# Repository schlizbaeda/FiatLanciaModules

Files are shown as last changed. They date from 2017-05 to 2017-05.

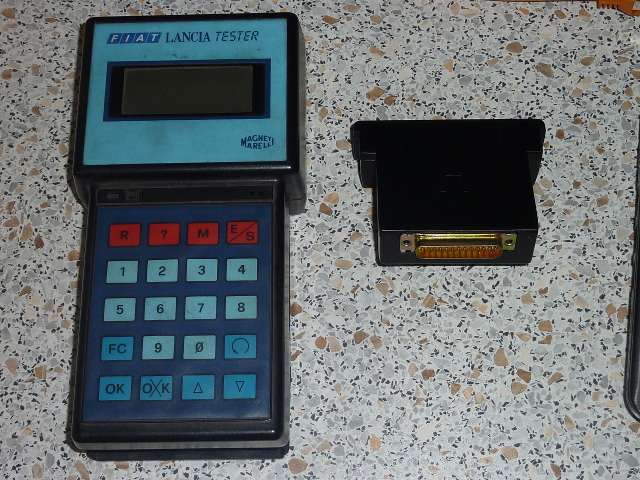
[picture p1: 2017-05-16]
Bilder/Titelbild.JPG

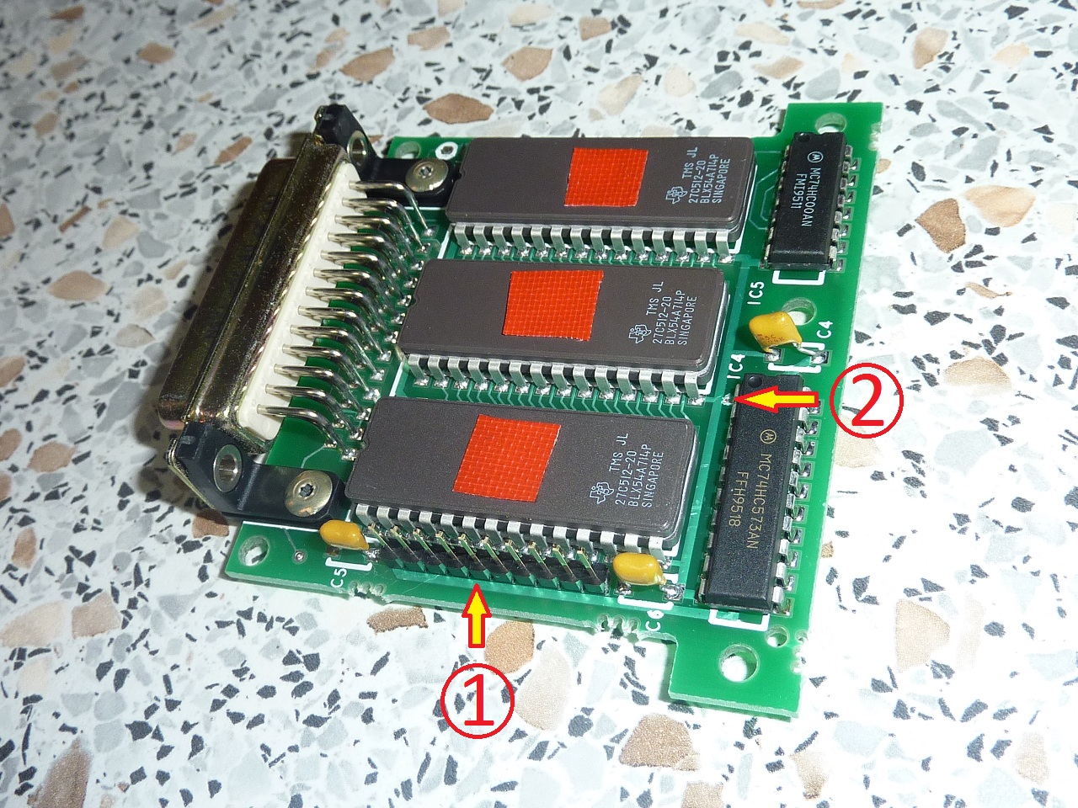
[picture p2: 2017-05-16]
Bilder/_Umbau01.jpg

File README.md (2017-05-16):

ACHTUNG:

Dieses Repository stammt weder vom Automobilhersteller "FIAT S.p.A.",
noch vom zum FIAT-Konzern gehörenden Automobilzulieferunternehmen 
"Magneti Marelli S.p.A."! Die Verwendung dieser Namen durch mich dient
lediglich der leichteren Zuordnung für den Leser, wofür die hier 
präsentierte Anleitung und weitere Daten dienen sollen.

# FiatLanciaModules
EPROM-Programmierung der Module für den Fiat/Lancia-Tester

In der Datei FL-Module_programmieren.pdf befindet sich eine Anleitung, wie 
aus vorhandenen EPROM-Modulen für den F/L-Tester aus den 90er-Jahren(?)
- die Moduldaten ausgelesen
- die Module (zum Widerbeschreiben) gelöscht 
- die Module neu programmiert

werden können.

Dieses GitHub-Repository enthält alle Dateien zur Erstellung dieser Doku-
mentation mittels LaTeX im Hauptverzeichnis sowie in den Unterverzeichnissen
Bilder, Kapitel und Layout

# Erstellung der pdf-Datei mittels LaTeX unter Ubuntu im Terminalfenster
$ sudo apt-get install texlive-full

$ pdflatex FL-Module_programmieren.tex

Während der Erstellung erscheint die Meldung

    l.180 \caption
                      {{\FLTester} und Memory}           
    ? 
mit blinkendem Cursor. Hier über die Tastatur R ENTER eingeben.

$ pdflatex FL-Module_programmieren.tex

Dieser zweite Aufruf ist in LaTeX erforderlich, um das Inhaltsverzeichnis
und die Verlinkungen des Dokumentes korrekt zu erstellen.

# Nachbau
Der Nachbau inkl. Schaltplänen ist in FL-Module_programmieren.pdf beschrieben.
Im Verzeichnis Hardware befinden sich weitere Informationen für den Nachbau:
- Layoutdaten für EAGLE
- IC-Datenblätter

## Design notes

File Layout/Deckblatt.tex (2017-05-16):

% -- Deckblatt.tex -----------------------------------------------------------
%
%   Gestaltung des Deckblattes der Bedienungsanleitung:  
%   - Einbinden und formatieren der Logos
%   - Bezeichnungen befinden sich in 'Meta.tex'   
% ------------------------------------------------------------------------------

\thispagestyle{empty} % von plain nach empty
\begin{titlepage}
\vspace*{-3cm}% vertikale negative Verschiebung
%%------------------------------------------------------------------------------
%%   Firmenlogo einfügen
%%------------------------------------------------------------------------------
\begin{figure}[h]
\centering

\end{figure}

\begin{center}
\LARGE{\textbf{\Dokumentart}}\\[1.5ex] 
\Large{\BezeichnungLang}\\[4ex]
%%------------------------------------------------------------------------------
%%   Titel der Bedienungsanleitung
%%------------------------------------------------------------------------------
\noindent\rule[1ex]{\textwidth}{3pt} % vertikaler Strich
%\huge{\textbf{\titel}}\\[1.5ex]      % TITEL DER ARBEIT
\textbf{\titel}\\[1.5ex]              % TITEL DER ARBEIT (lange Überschrift)
\noindent\rule[1ex]{\textwidth}{3pt} 
%\LARGE{\textbf{\untertitel}}\\[6ex]
%\LARGE{\textbf{\art}}\\[1.5ex]
%\Large{im Fachgebiet \fachgebiet}
\\[2ex]

\normalsize
%%------------------------------------------------------------------------------
%%   Bild
%%------------------------------------------------------------------------------
\begin{figure}[h]
\centering

\end{figure}

%%------------------------------------------------------------------------------
%%   CE und Firmenadresse
%%------------------------------------------------------------------------------
\begin{tabular}{p{3cm} p{8cm} p{3cm}}\\ % die beiden 0.5cm breiten "TabellensSpalten" sind eigentlich latex-unwürdiges Gepfriemel! Ich kann's aber nicht besser!
\hline
\parbox[c]{75px}{} & \textbf{Module für {\FLTester} programmieren} Datum: 23.10.2016 & \parbox[c]{75px}{}\\
\hline
\end{tabular}

\end{center}

Diese Anleitung wurde mit dem Textsatzsystem \LaTeX\ erstellt.
%% Das trifft hier nicht zu:
%\textbf{}\\
%Das Bild auf dem Fernsehgerät stammt aus dem Video zu folgendem Musikstück:\\
%\texttt{\textbf{Riegler Hias feat. d' Hundskrippln} \textit{Gloana Bauer}} bei 0:15\\
%\url{http://www.hundskrippln.de/#filme}
\end{titlepage}

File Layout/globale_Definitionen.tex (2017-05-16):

% Meta-Informationen -----------------------------------------------------------
%   Definition von globalen Parametern, die im gesamten Dokument verwendet
%   werden können (z.B auf dem Deckblatt etc.).
%
%   ACHTUNG: Wenn die Texte Umlaute oder ein Esszet enthalten, muss der folgende
%            Befehl bereits an dieser Stelle aktiviert werden:
%            \usepackage[latin1]{inputenc}
% ------------------------------------------------------------------------------
\newcommand{\titel}{Umprogrammierung von EPROM-Modulen für den {\FLTester}}
\newcommand{\untertitel}{}%{TODO: und hier kommt der Untertitel}
\newcommand{\Bezeichnung}{Module für {\FLTester} programmieren}
\newcommand{\BezeichnungLang}{EPROM-Module für {\MarelliTester} ändern}
%\newcommand{\Version}{V0.1}
\newcommand{\Dokumentart}{A N L E I T U N G}
\newcommand{\autor}{schlizbäda}
\newcommand{\jahr}{2016}

% verwendete Hardware
\newcommand{\FLTester}{F/L-Tester}
\newcommand{\MarelliTester}{Fiat Lancia Tester (Magneti Marelli)} % TODO: Internetbilder "FIAT" "LANCIA" "Tester" "MagnetiMarelli" 
\newcommand{\Batronix}{Batronix BARLINO II} % Programmiergerät
% verwendete Software
\newcommand{\ProgExpress}{Prog-Express} % Batronix Programmiersoftware

%%Steuerelemente von Software:
%\newcommand{\prompt}[1]{\Code{\textit{#1}}}
%\newcommand{\filenam}[1]{\Code{#1}}
%
%\newcommand{\button}[1]{\Code{[{#1}]}}
%\newcommand{\menuitem}[1]{\textbf{\textit{"{#1}"}}}
%\newcommand{\checkbox}[1]{\textbf{\textit{"{#1}"}}}

%Smileys:
\newcommand{\smiley}[1]{}}

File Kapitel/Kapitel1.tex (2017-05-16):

\chapter{Einführung}
\label{cha:Einfuehrung}

\section{ACHTUNG}
{\LARGE Stand 16.05.2017

Leider sehe ich mich derzeit nicht in der Lage, meine Erkenntnisse rechtlich 
gefahrlos zu veröffentlichen! Ich werde versuchen, über offizielle Stellen des
FIAT-Konzerns die Erlaubnis zu erlangen, dies doch veröffentlichen zu dürfen.
Bis zur Klärung dieses Sachverhalts sehe ich mich gezwungen,
meine Arbeit vorerst teilweise zurückzuziehen.

Vielen Dank für Ihr Verständnis.

schlizbaeda@gmx.de}
\newpage

\section{Kurzbeschreibung und technische Daten des {\FLTester}s}
Der {\FLTester} ist ein elektronisches Diagnosegerät für Kraftfahrzeuge
der FIAT-Gruppe: Es ist ein tragbarer Computer (basierend auf dem
8bit-Mikroprozessor Hitachi HD6303RP), der den Datenaustausch mit den in
den Fahrzeugen eingebauten elektronischen Steuergeräten ermöglicht.\\
Die Software (Prüfprogramm) wird dem {\FLTester} über ein EPROM-Modul
zugeführt, das abhängig vom zu prüfenden Steuergerätetyp ausgewählt
und gesteckt werden muss.

Auszug aus der Original-Betriebsanleitung:\\
\textit{Das Diagnosegerät kann die betreffenden Daten des zu
analysierenden Systems auswerten und speichern, und so dem Operator über
ein Display geeignete Instruktionen zur Analyse eventueller
Fehlfunktionen und zur Auffindung der beschädigten Komponenten geben.\\
Der Tester erkennt automatisch den Steuergerätetyp, an den er
angeschlossen ist. Die Verbindung mit dem Bord-Steuergerät erfolgt durch
einen spezifischen Standardstecker (siehe Abb. 1).\\
Das Testgerät kann außerdem die Informationen an verschiedene Terminals
weiterleiten (Drucker, Monitor, zentrale Computer u.\,s.\,w.).}

\subsection*{Technische Daten}
\begin{tabular}{ll}
Stromversorgung:          & 7 -- 30V dc\\
Arbeitstemperatur:        & 0 -- 70°C\\
Format der Diagnosecodes: & NRZ, PCM, Zweiphasen\\
Eingangsfrequenz:         & 1Hz -- 10kHz\\
Zusätzlicher Ausgang:     & RS232 (50 -- 19200bps)\\
Display:                  & alphanumerisches LCD, 4 Zeilen à 16 Zeichen\\
CPU:                      & Hitachi HD6303RP (8bit, 1MHz)\\
Speicherkapazität RAM:    & 2K/8KByte mit permanenter Datenspeicherung\\
Speicherkapazität ROM:    & max. 136KByte (abhängig vom EPROM-Modul)\\
\end{tabular}
\\

Der Aufbau entspricht dem technischen Stand der Heimcomputer aus den
frühen 1980er-Jahren wie \zB dem Commodore 64. Die Entwicklung des
{\FLTester}s dürfte etwa um 1990 erfolgt sein. Auf einigen vorliegenden
Modulen lassen die Beschriftungen auf ein Herstelldatum von 1995 \bzw
1996 schließen. 

\section{Aufbau der EPROM-Module}
Die EPROM-Module bestehen aus einer Leiterplatte, die mit drei EPROM-ICs
vom Typ 27C512 (512kBit, 64KByte) ist. Bei IC1 sind die drei oberen
Adressleitungen (A13, A14 und A15) fest mit GND verbunden, so dass
dieser EPROM nur mit max. 8KByte Daten befüllt werden kann. Um dem
{\FLTester}, der eigentlich nur 64KByte adressieren kann, einen größeren
Programmspeicher zur Verfügung zu stellen, befindet sich auf den Modulen
eine zusätzliche ChipEnable-Logik, die über einen 74HC00 (NAND-Gatter)
umgesetzt ist. Damit kann der {\FLTester} über dieses "`Banking"' bis zu
136KByte ROM-Speicher adressieren.

Von den Leiterplatten der EPROM-Module gibt es mindestens drei
Layoutvarianten:\\
\begin{tabular}{ll}
\textbf{79 54 33 50}: & Bestückung mit kleineren EPROMs bis M27C256\\
                      & wurde für die ersten Module mit den niedrigen Nummern verwendet\\
                      & \zB M1C, M2B, M3B, \textbf{M6B}, M7A \ua(?)\\
\textbf{79 63 15 40}: & Bestückung mit 64KByte-EPROMs (M27C512)\\
                      & Diese Variante wurde schaltungstechnisch (noch) nicht untersucht\\
                      & gefunden auf den Modulen M12A und M15A\\
                      & $\rightarrow$ Die Daten konnten problemlos ausgelesen werden.\\
\textbf{79 63 82 40}: & häufigstes Modul, Bestückung mit 64KByte-EPROMs (M27C512)\\
                      & vermutlich der aktuelle Designstand\\
                      & Alle späteren Module (\zB \textbf{M23A}) verwenden dieses Layout\\
\end{tabular}
\\

Die Stromlaufpläne der EPROM-Module befinden sich im Anhang.

\section{Liste der EPROM-Module}
\begin{table}[!h]
%\centering
\renewcommand{\arraystretch}{1.2}
\begin{tabular}{|l|l|l|}
\hline%\toprule[2pt]
\textbf{Modul} & \textbf{Bemerkung}              & \textbf{Fahrzeugtyp(en) (unvollständig)}\\ 
\hline%\midrule[2pt]
M1C            & IAW, SPI-GM                     & Delta GT i.e. 8V Kat\\
\hline
M2B            & Digiplex 2, Microplex           & \\
\hline
M3B            & Bosch Monojetronic, L3.1 / L3.2 & \\
\hline
M4B            & S.C.S. / S.I. Fahrwerk          & \\
\hline
\textbf{M6B}   & IAW USA '83                     & Delta HF Turbo / Integrale\\
               &                                 & EVO I (ohne Kat)\\
               &                                 & EVO 8V mit Kat\\
\hline%\bottomrule[2pt]
\end{tabular}
\vspace{0.5cm}
\caption{{\FLTester} und Memory}
\label{tab:Modulliste1}
\end{table}

\begin{tabular}{|l|l|l|}
\hline%\toprule[2pt]
\textbf{Modul} & \textbf{Bemerkung}              & \textbf{Fahrzeugtyp(en) (unvollständig)}\\ 
\hline%\midrule[2pt]
M7A            & Girling ABS 2/2                 & Tipo 2l.GT / Tempra Bj. 91\\
\hline
M8B            & ECVT Automatikgetriebe          & \\
\hline
M9A            & Bosch KE3.3                     & \\
\hline
M10A           & Automatik-Getriebe VW AG4       & \\
\hline
M11B           & EGR Diesel                      & \\
\hline
M12B           & Bosch ABS 2E / 2SI              & Croma / Coupe Mai 96\\
\hline
M13A           & Bosch M1.7 / M2.7 Lancia        & \\
\hline
M14A           & autom. Heizung, Klimaanlage     & \\
\hline
M15A           & Niveauregulierung               & Tempra S.W.\\
\hline
M18A           & Airbag, Diebstahlwarnanlage,    & Croma / Thema\\
               & Sitzverstellung                 & \\
\hline
M19A           & IAW - P8                        & \\
\hline
M20A           & Digiplex 2/2S, Microplex/S      & \\
\hline
M21B           & Weber - SPI                     & Punto 60 (alt)\\
\hline
\textbf{M23A}  & IAW - P8 (selbstadaptierend)    & Delta EVO II 16V Kat\\
\hline
M24A           & Bosch M1.7 / M2.7 Fiat          & \\
\hline
M25B           & Bosch Monomotronic MA1.7 u. MA1.7.3 & \\
\hline
M26A           & elektronisch gesteuertes Automatikgetriebe ZF & \\
\hline
M28A           & IAW 8F. 52 & \\
\hline
M29A           & Fiat Airbag, Diebstahlwarnanlage/Wegfahrsperre & \\
               & Lancia Diebstahlwarnanlage (ohne R40/41/42)    & \\
\hline
M30A           & Bosch ABS 2SI                   & Dedra S.W. 4x4\\
\hline
M31A           & Bendix ABS                      & Ducato / Ulysse / Zeta / Scudo ab 94\\
\hline
M32A           & IAW                             & Ducato / Ulysse\\
\hline
M33A           & Multipoint GM                   & \\
\hline
M34A           & Bosch MSA 11 Turbo Diesel       & \\
\hline
M35A           & Bosch MP3.2                     & Ulysse Turbo / Zeta\\
\hline
M36B           & Motronic M2.10.3                & \\
\hline
M38A           & Diagnose IGE, Info-Center       & \\
\hline
M39A           & el. Automatik ZF, AISIN-Automatik & \\
\hline
M40A           & Airbag, TRW, Diebstahlsicherung & Sipea\\
\hline
M41A           & ABS5.0, Servotronic             & Lancia Kappa bis 96\\
\hline
M42B           & Superverriegelung/Diebstahlsicherung & Ulysse / Zeta\\
\hline
M43A           & MFI-0 Hitachi                   & Barchetta\\
\hline
M44A           & Motronic M3.7, M2.7             & \\
\hline
M45A           & Fiat-Code / Lancia-Code         & Punto (Einspritzung und Codeadapter)\\
\hline
M46A           & Bosch M1.7 / M2.7, Fiat-Code    & \\
\hline%\bottomrule[2pt]
\end{tabular}
\vspace{0.5cm}
\caption{{\FLTester} und Memory}
\label{tab:Modulliste2}
\end{table}

\begin{tabular}{|l|l|l|}
\hline%\toprule[2pt]
\textbf{Modul} & \textbf{Bemerkung}              & \textbf{Fahrzeugtyp(en) (unvollständig)}\\ 
\hline%\midrule[2pt]
M47A           & ABS-Ate MK20                    & alle Modelle (Bravo / Brava)\\
\hline
M48A           & IWA-IAF13, Fiat-Code            & 1,6l (90PS)\\
\hline
M49A           & Bosch Motronic M2.10.4, Fiat-Code & HGT\\
\hline
M50A           & Airbag, Alarm ICIT '95          & alle Modelle\\
\hline
M52A           & Klimaanlage Behr                & Lancia Z\\
\hline
M53A           & Lucas Diesel DPC                & Marea / Bravo / Brava\\
\hline
M54A           & Aisin Automatik                 & \\
\hline
M55A           & ECVT Automatikgetriebe          & Punto Selectra\\
\hline
M56A           & Bosch ABS5.3                    & Coupe / Punto ab Mai 96\\
\hline
M57A           & IAW 16F.ET                      & Punto / Cinquecento (neuere)\\
\hline
M58A           & Airbag, Gurtstraffer            & Ulysse / Scudo / Zeta\\
\hline
M59A           & IAW 18F                         & Punto 1,2 16V\\
\hline
M60A           & Diesel Lucas                    & Lancia Z.2.1 TD\\
\hline
M61A           & Klimaanlage Borletti            & Marea\\
\hline
M62A           & ABS Lucas                       & \\
\hline
M63A           & Diesel Lucas DPC                & Marea TD\\
\hline
M65A           & Infosender Datenübertragung     & Kappa \\
\hline%\bottomrule[2pt]
\end{tabular}
\vspace{0.5cm}
\caption{{\FLTester} und Memory}
\label{tab:Modulliste3}
\end{table}

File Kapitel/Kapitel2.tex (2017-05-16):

\chapter{Programmierung der EPROM-Module}
\label{cha:Programmierung}

In diesem Kapitel wird beschrieben, welche Schritte notwendig sind, um
die EPROM-Module auszulesen, zu löschen und neu zu programmieren.

\section{Hardwarevoraussetzungen}
Folgende Geräte werden benötigt, um eine Neuprogrammierung der
EPROM-Module durchführen zu können (Stand 2012):\\
\begin{table}[!h]
%\centering
\renewcommand{\arraystretch}{1.2}
\begin{tabular}{|l|l|l|l|}
\hline
\textbf{Gerät}           & \textbf{Handelsbezeichnung} & \textbf{Lieferant} & \textbf{Bestellnummer}\\
\hline
UV-Löschgerät            & H-TRONIC ProMA              & reichelt           & EPROMLÖSCHER\\
                         & UV-Licht-Löschgerät         &                    & \\
\hline
Programmiergerät         & {\Batronix}                 & Batronix           & BX32P-II\\
\hline
Adapter für EPROM-Module & Eigenbau                    & ---                & \\
\hline
PC/Laptop mit Windows 7  & IBM-kompatibel              & ---                & \\
\hline
\end{tabular}
\vspace{0.5cm}
\caption{erforderliche Hardware}
\label{tab:erforderlicheHardware}
\end{table}

\begin{figure}[h]
\centering

\caption{UV-Löschgerät für EPROMs (eingebaut in eine Holzkiste)}
\label{fig:UVLoeschgeraet}
\end{figure}

\begin{figure}[h]
\centering

\caption{EPROM-Programmiergerät}
\label{fig:Programmiergeraet}
\end{figure}

\begin{figure}[!h]
\centering

\caption{Adapter zur Programmierung der EPROMs auf den Modulen}
\label{fig:Adapter}
\end{figure}

\section{Vorbereitung und Umbau der Module für Zugriff über \Batronix}
{\LARGE Abschnitt entfernt}
%Da auf den EPROM-Modulen bis zu drei EPROMs fest verlötet sind, aber auf
%dem verwendeten Programmiergerät {\Batronix} die Bausteine normalerweise
%direkt auf den Nullkraftsockel gesteckt werden müssen, musste eine
%Adaptierung gebaut werden, an die das EPROM-Modul angesteckt werden
%kann. Die zu programmierenden EPROMs (IC1, IC2 und IC3) auf dem Modul
%können somit über den 25-poligen SUB-D-Stecker des Moduls und über eine
%im Modul nachgerüstete 10-polige Stiftleiste kontaktiert werden.\\
%Mittels Kippschaltern auf der Adaptierung wird der zu programmierende
%EPROM (IC1, IC2 oder IC3) ausgewählt. Dabei wird das Signal CE (Pin 20)
%so beschaltet, wie es auch im Realbetrieb über den {\FLTester} erfolgt.\\
%Ferner müssen die Ausgänge des Latchbausteins IC4 (74HC573) während der
%Programmierung in den hochohmigen Tristate-Modus geschaltet werden,
%damit dessen am Daten- und Adressbus angeschlossenen Ausgänge nicht
%stören. Dies wird durch einen leichten Umbau der Module erreicht:
%Eine als Leiterbahn ausgeführte feste Masseverbindung des Enable-Signals
%von IC4 (Pin 1) wird aufgetrennt und durch einen PullDown-Widerstand
%(4k7) ersetzt. Das Enable-Signal ist im Normalbetrieb über den PullDown
%weiterhin mit Masse verbunden und damit aktiviert. Während der
%Programmierung kann Enable auf +5V geschaltet werden, um die Ausgänge
%von IC4 in den gewünschten Tristate-Modus zu bringen.\\
%Die restlichen Signale des EPROMs sind als 1:1-Verbindungen ausgeführt.

\subsection{Programmieradapter für die EPROM-Module}
Der Aufbau einer passenden Adaptierung für den Programmiervorgang kann
auf einer Lochrasterplatine mit 19 x 15 Löchern aufgebaut werden. Dabei
ist nur darauf zu achten, dass sich der Einbauplatz X100 rechts oben
befindet, damit der Adapter problemlos in den Nullkraftsockel des
Programmiergerätes {\Batronix} gesteckt werden kann, wie es in Abbildung
\ref{fig:AdapterInProgger} dargestellt ist.

\begin{figure}[h]
\centering

\caption{Adapter auf Programmiergerät {\Batronix}}
\label{fig:AdapterInProgger}
\end{figure}

Die Kontaktierung erfolgt...
% einerseits über eine 25-polige SUB-D-Buchse
%(X1), die an den SUB-D-Stecker des EPROM-Moduls angesteckt wird.
%Weiterhin ist eine Flachbandleitung (X2) für die Adressleitungen A0-A7
%auf eine 10-polige Stiftleiste im Inneren des Moduls zu stecken. Dafür
%muss das EPROM-Modul wie im Abschnitt \ref{subsect:Umbau} beschrieben
%umgebaut werden.

{\LARGE Abschnitt entfernt}

Die Programmierung der bis zu drei in den Modulen verbauten EPROMs
erfolgt für jeden Baustein einzeln und getrennt. Sowohl in der
Programmiersoftware {\ProgExpress} als auch auf dem Adapter muss der zu
programmierende Baustein (IC1, IC2 oder IC3) richtig ausgewählt werden.
Auf dem Programmieradapter erfolgt die Auswahl über die richtige
Schalterstellung der beiden Kippschalter S101 und S102:

\begin{figure}[h]
\centering

\caption{Schaltplan des Programmieradapters}
\label{fig:Programmieradapter_sch}
\end{figure}

\begin{figure}[!h]
\centering



\caption{Layout des Programmieradapters}
\label{fig:Programmieradapter_layout}
\end{figure}

S101 ermöglicht die Auswahl "`IC1"' oder "`IC2+3"'. In der Stellung 
"`IC1"' wird immer IC1 des Moduls angesprochen. Es ist egal in welcher
Stellung S102 steht.\\
S102 dient der Auswahl "`IC2"' oder "`IC3"'. Dabei darf S101
\textit{nicht} in Stellung "`IC1"' stehen!\\
Siehe Abbildung \ref{fig:Adapter}

In den Abbildungen \ref{fig:Programmieradapter_sch} und 
\ref{fig:Programmieradapter_layout} werden der Schaltplan und eine
mögliche Umsetzung auf einer Lochrasterplatine illustriert. Abbildung
\ref{fig:Programmieradapter_Fotos} zeigt weitere Fotos von der fertigen
Lochrasterplatine des Programmieradapters.

\begin{figure}[!h]
\centering




\caption{Fotos des Programmieradapters}
\label{fig:Programmieradapter_Fotos}
\end{figure}

\newpage
\subsection{Umbau der Leiterplatten der EPROM-Module}
\label{subsect:Umbau}
Damit die EPROM-Module über das hier beschriebene Verfahren neu
programmiert werden können, sind folgende Umbaumaßnahmen an den Modulen
vorzunehmen:

\begin{tabular}{ll}
1. & ... (entfernt)\\
2. & ... (entfernt)\\
3. & ... (entfernt)\\
%1. & Einlöten der 10-poligen Stiftleiste an einem vorhandenem Einbauplatz\\
%2. & Auftrennen der Leiterbahn für die Masseverbindung zu IC4 Pin 1\\
%3. & PullDown-Widerstand (4k7) zu IC4 Pin 1 für Normalbetrieb\\
%   & und Vcc-Verbindung für Programmierung herstellen\\
\end{tabular}

Die Umbaumaßnahmen sind in Abbildung \ref{fig:Umbau} dargestellt.

\section{Softwareinstallation Batronix Prog-Express (Windows)}
Die Software {\ProgExpress} für das Programmiergerät {\Batronix} erfolgt
unter Windows über die beiliegende CD, auf welcher die Version 1.6
(Stand 2012) der Software enthalten ist. Der Installationsassistent für
Windows ist einfach und selbsterklärend. Für die ebenfalls auf der CD
vorhandene Linux-Variante muss zusätzlich die %quelloffene 
Linux-Implementierung des .NET-Frameworks, \textit{Mono} installiert
werden (\url{http://www.mono-project.com}).

\begin{figure}[!b]
\centering


\caption{umgebaute Leiterplatte eines EPROM-Moduls}
\label{fig:Umbau}
\end{figure}

\section{Auslesen der Module zur Datensicherung}
\label{sect:Auslesen}
Wenn ein Koffer mit EPROM-Modulen für den {\FLTester} gekauft wurde, ist
es zunächst erforderlich, die Daten auf den Modulen auszulesen und auf
dem  PC zu sichern. 
\begin{bclogo}[logo = \bclampe, noborder = true]{Hinweis}
Die EPROM-Module müssen \textit{vor} dem Auslesen der Moduldaten so
umgebaut werden, wie in Kapitel \ref{subsect:Umbau} beschrieben!
\end{bclogo}
Der Anschluss des umgebauten Moduls muss wie in Abbildung
\ref{fig:Modulanschluss} dargestellt erfolgen:

{\LARGE Teilabschnitt entfernt}

%\begin{itemize}
%\item{Das Programmiergerät {\Batronix} an einen USB-Port des PCs anschließen.}
%\item{Die Programmieradaptierung in den Nullkraftsockel des Programmiergerätes stecken. Dabei auf die Ausrichtung aus Abbildung \ref{fig:AdapterInProgger} achten.
%\item{Die SUB-D-Stecker sind anzustecken}
%\item{Die Flachbandleitung muss auf die eingelötete Stiftleiste des Moduls gesteckt werden. Für die richtige Pinzuordnung muss das Flachbandkabel \textit{ohne Drehung} gesteckt werden!}
%\end{itemize}

\begin{figure}[h]
\centering

\caption{Anschluss eines EPROM-Moduls über den Programmieradapter am Programmiergerät {\Batronix}}
\label{fig:Modulanschluss}
\end{figure}

Beim Auslesen der Moduldaten sind...

{\LARGE Abschnitt entfernt}
% drei Leseläufe für IC1, IC2 und IC3
%erforderlich. Auf IC1 können nur 8KByte gespeichert (und ausgelesen)
%werden, daher muss in den Chip-Optionen für IC1 der auszulesende
%Speicherbereich von Startadresse 0 bis Endadresse 0x1FFF (8191 dez.)
%gesetzt werden!\\
%IC2 und IC3 enthalten Daten im gesamten Speicherbereich (64KByte) des
%Bausteins (27C512). Es gibt auch Leiterplatten mit kleineren EPROMs
%(\zB 27C256 mit 32KByte). In diesem Falle kann der Bausteintyp entweder
%über die Funktion "`Chip Autoerkennung"' der Programmiersoftware
%ermittelt werden, dann wird seine Speichergröße von der Software
%automatisch korrigiert oder der Speicherbereich wird auch hier manuell
%eingeschränkt.\\
%Die ausgelesenen Daten werden zweckmäßigerweise in einem Ordner mit dem
%Modulnamen (\zB "`M23A"') unter den Dateinamen \texttt{IC1.bin},
%\texttt{IC2.bin} und \texttt{IC3.bin} abgelegt.

\subsection*{Auslesevorgang über die Software {\ProgExpress}}
Die Oberfläche der Software {\ProgExpress} ist im Wesentlichen in drei
Spalten konzipiert. Links befinden sich die möglichen Aktionen als
Piktogramme. In der Mitte (Hauptteil) wird die gewählte Aktion im Detail
angezeigt: Oben die genaue Parametrierung und im unteren Teil die
Einzelschritte der Aktion. Durch Anklicken der einzelnen Elemente können
notwendige  Anpassungen vorgenommen werden. Der rechte Teil enthält ein
Log-Fenster, in dem alle durchgeführten Aktionen mit Ergebnis angezeigt
werden.

\begin{figure}[h]
\centering

\caption{Grundlegende Softwareeinstellungen zum Auslesen der EPROM-Daten}
\label{fig:SoftEinstellungen}
\end{figure}

Zum Auslesen der Moduldaten sind in  folgende Schritte
notwendig:
Zunächst muss in der Software im linken Bereich die richtige Aktion, 
hier das Auslesen der Chipdaten durch Anklicken des entsprechenden
Piktogramms gewählt werden.\\


{\LARGE Abschnitt entfernt}
%In bestimmten Fällen, insbesondere bei IC1, von dem aufgrund seiner
%Beschaltung in den EPROM-Modulen nur ein Block von 8KByte adressiert
%werden kann, muss in den Chip-Optionen die Speichergröße angepasst
%werden, siehe Abbildungen \ref{fig:SoftEinstellungenIC1} und
%\ref{fig:SoftEinstellungenIC1addr}\\
%Bei IC2 und IC3 müssen dagegen die kompletten Speicherbereiche
%ausgelesen werden! Dazu vor dem Ausleseprozess in den Chip-Optionen die
%Einschränkung des Adressbereichs von IC1 wieder deaktivieren. Die
%Software {\ProgExpress} verwendet bei der richtigen Auswahl des Chiptyps
%die richtige Speichergröße.

\begin{figure}[h]
\centering

\caption{Softwareeinstellungen zum Auslesen von IC1 (max. 8KByte)}
\label{fig:SoftEinstellungenIC1}
\end{figure}

Auf den einzelnen Modulen können folgende EPROM-Typen verbaut sein:\\
\begin{tabular}{ll}
M27C64  & 8KByte Speicherkapazität\\
M27C256 & 32KByte Speicherkapazität\\
M27C512 & 64KByte Speicherkapazität\\
\end{tabular}
\\ \\ Der Auslesevorgang dauert pro Baustein nur ca. 1 Sekunde.
\begin{bclogo}[logo = \bclampe, noborder = true]{Hinweise}
Um die \textit{vollständigen} Daten eines EPROM-Moduls zu erhalten,
müssen logischerweise \textit{alle} bestückten EPROMs (IC1, IC2 und IC3)
ausgelesen werden!\\
Für IC2 und IC3 muss unbedingt darauf geachtet werden, deren
\textit{gesamten} Speicherbereich auszulesen!\\
Die Schalter S101 und S102 auf dem Programmieradapter sind \textit{vor}
dem Auslesevorgang in die richtige Schaltstellung zu bringen!
\end{bclogo}

\begin{figure}[h]
\centering

\caption{Parametrierung des gewünschten Adressbereichs von IC1 (8KByte)}
\label{fig:SoftEinstellungenIC1addr}
\end{figure}

\section{Löschen der Module mit UV-Licht}
\label{sect:Loeschen}
In den EPROM-Modulen wurden die klassischen EPROMS verbaut, die nur mit
UV-Licht gelöscht werden können. Dazu wird ein EPROM-Löschgerät mit
UV-Lampe (Abbildung \ref{fig:UVLoeschgeraet}) verwendet, das aus
Sicherheitsgründen in eine lichtundurchlässige Holzkiste eingebaut
wurde.
\begin{bclogo}[arrondi = 0.2, logo = \bcinfo, ombre = true, epOmbre = 0.25, couleurOmbre = black !30,blur]{Achtung}
Das vom EPROM-Löschgerät abgegebene UV-Licht kann die Haut und vor allem
die Augen schwer schädigen! Daher darf das Löschgerät \textbf{nur im
geschlossenen Zustand} betrieben werden!
\end{bclogo}
Vor dem Programmieren eines EPROM-Moduls mit neuen Daten müssen zunächst
die vorhandenen Daten von den EPROMs gelöscht werden. Dazu muss der
Deckel der Holzkiste abgenommen werden und eine oder zwei Leiterplatten
von geöffneten EPROM-Modulen über die UV-Lampe des Löschgerätes gelegt
werden. Dabei darf nicht vergessen werden, die Lichtschutzaufkleber von
den runden Quarzglasfenstern der EPROMs zu entfernen!\\
Vor dem Einschalten des Löschgerätes muss aus Gründen des Eigenschutzes
unbedingt der Holzdeckel geschlossen werden.\\
Der Löschvorgang unter UV-Licht dauert ca. 20 -- 30 Minuten. Bei
kürzeren Belichtungszeiten können einzelne Bits stehen bleiben, die dann
bei der nachfolgenden Neuprogrammierung stören! Nach dem Löschvorgang
sollte vor der Neuprogrammierung nochmals für mindestens die gleiche
Zeit gewartet werden, um die soeben gelöschten EPROMs "`abkühlen"' zu
lassen.
\begin{bclogo}[logo = \bclampe, noborder = true]{Hinweis}
Technisch gesehen erfolgt das Löschen über eine Ionisation des
Halbleitermaterials durch das UV-Licht, die die gespeicherten
Ladungsträger abfließen lässt. Diese Ionisation kann nach dem Abschalten
des UV-Lichtes noch einige Zeit anhalten, wenn auch in geringerem Maße,
aber möglicherweise dafür ausreichend, dass die durch eine unmittelbar
folgende Programmierung neu aufgebrachten Ladungsträger zumindest
teilweise wieder abfließen. Dies kann sich nach außen dann durch 
kippende Bits oder eine verkürzte Datenlebensdauer bemerkbar machen.
\end{bclogo}
Ein vollständig gelöschtes EPROM enthält nur Bits mit dem binären Wert
"`1"'. Beim Programmiervorgang werden ausschließlich "`0"'-Bits
programmiert, die "`1"'-Bits bleiben leer ("`unprogrammiert"'). Details
zur Technologie von EPROMs befinden sich hier:\\
\url{https://de.wikipedia.org/wiki/Erasable_Programmable_Read-Only_Memory}

\section{Programmieren der Module mit (neuen) Daten}
{\LARGE Abschnitt entfernt}

%Auch beim Programmieren von EPROM-Modulen sind drei Durchläufe für IC1,
%IC2 und IC3 erforderlich. Aufgrund der internen Beschaltung im Modul
%können auf IC1 nur 8KByte gespeichert werden, daher muss in den
%Chip-Optionen für IC1 der zu programmierende Speicherbereich von
%Startadresse 0 bis Endadresse 0x1FFF (8191 dez.) gesetzt werden!\\
%IC2 und IC3 können dagegen über ihren gesamten Speicherbereich
%adressiert und programmiert werden.\\
Grundsätzlich gelten die für das Auslesen der EPROM-Module relevanten
Punkte (siehe Kapitel \ref{sect:Auslesen}) auch für die Programmierung.

\subsection*{Programmiervorgang über die Software {\ProgExpress}}
Zum Programmieren der Moduldaten sind in  folgende Schritte
notwendig:
Zunächst muss in der Software im linken Bereich die richtige Aktion, 
hier das Programmieren der Chipdaten durch Anklicken des entsprechenden
Piktogramms gewählt werden.\\


Vor der Programmierung sollte unbedingt kontrolliert werden, ob in der
Software die richtige Programmierdatei gewählt wurde und ob die Schalter
S101 und S102 auf dem Programmieradapter in der richtigen Stellung sind.
Während solche Fehler beim Auslesen -- sofern rechtzeitig bemerkt --#
noch relativ unproblematisch sind, sollten sie beim Programmieren auf
jeden Fall vermieden werden, da ein falsch programmierter EPROM erst
wieder \textit{mühsam} gelöscht werden muss (siehe Kapitel
\ref{sect:Loeschen})!

\begin{figure}[h]
\centering

\caption{Softwareeinstellungen zum Programmieren von IC2}
\label{fig:SoftEinstellungenIC2}
\end{figure}

Der Programmiervorgang dauert nur wenige Sekunden, ist aber etwas
langsamer als der Auslesevorgang. Wichtig ist der Schritt "`Leertest"'
vor der Programmierung. Dort wird überprüft, ob wirklich jede
Speicherstelle des EPROMs gelöscht ist, \dahe nur "`1"'-Bits enthält.
Wenn dies nicht der Fall ist, muss das Modul zuvor erst gelöscht werden!
Diese Prüfung und der Vergleich der Chipdaten stellen sicher, dass die
programmierten Daten wirklich korrekt im EPROM abgelegt sind.

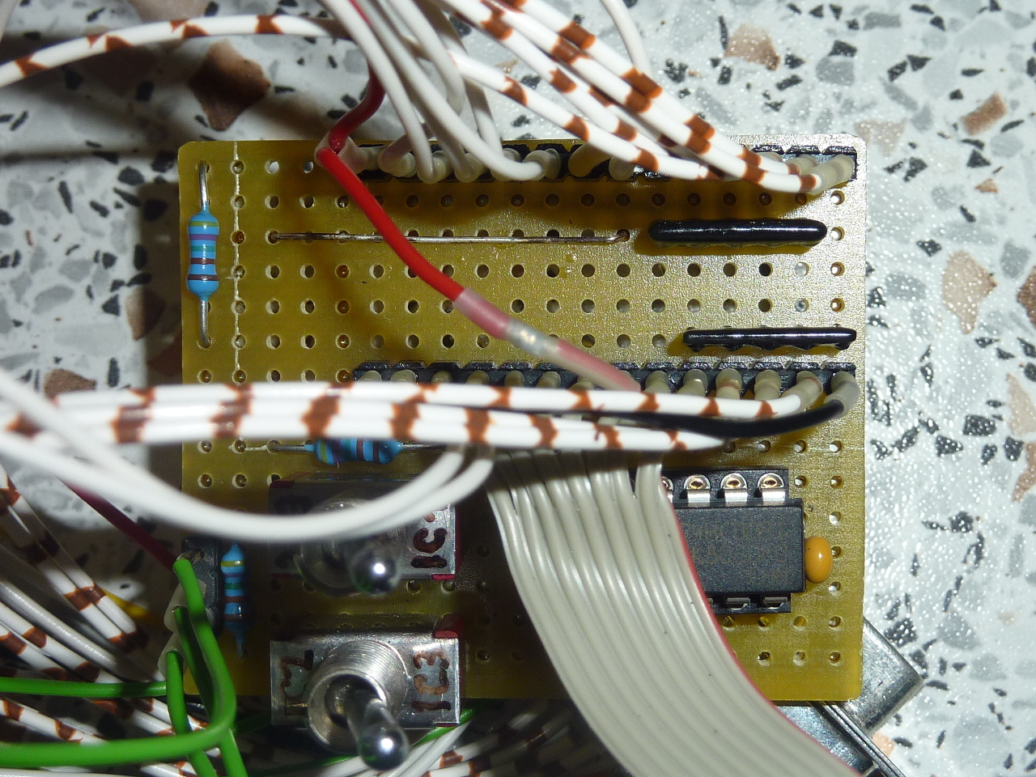
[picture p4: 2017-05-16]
Bilder/Adapter03.jpg

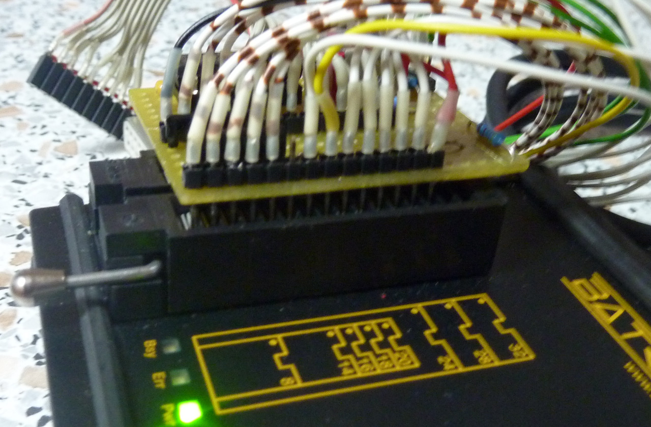
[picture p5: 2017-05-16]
Bilder/Adapter_auf_Programmiergeraet.jpg

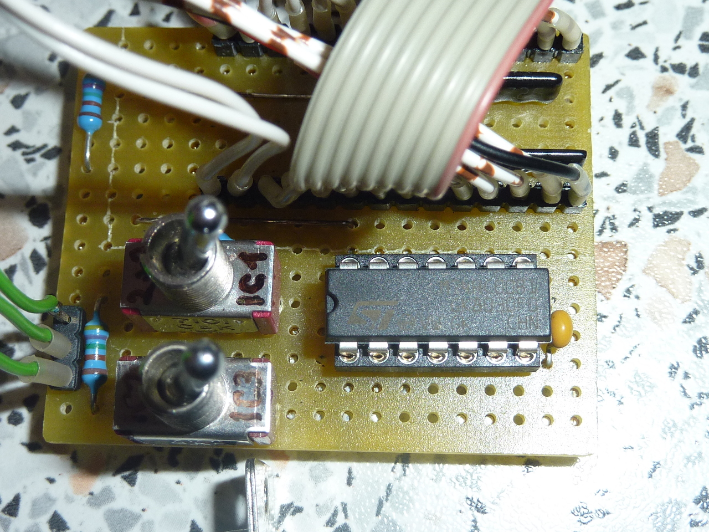
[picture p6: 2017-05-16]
Bilder/Adapter04.jpg

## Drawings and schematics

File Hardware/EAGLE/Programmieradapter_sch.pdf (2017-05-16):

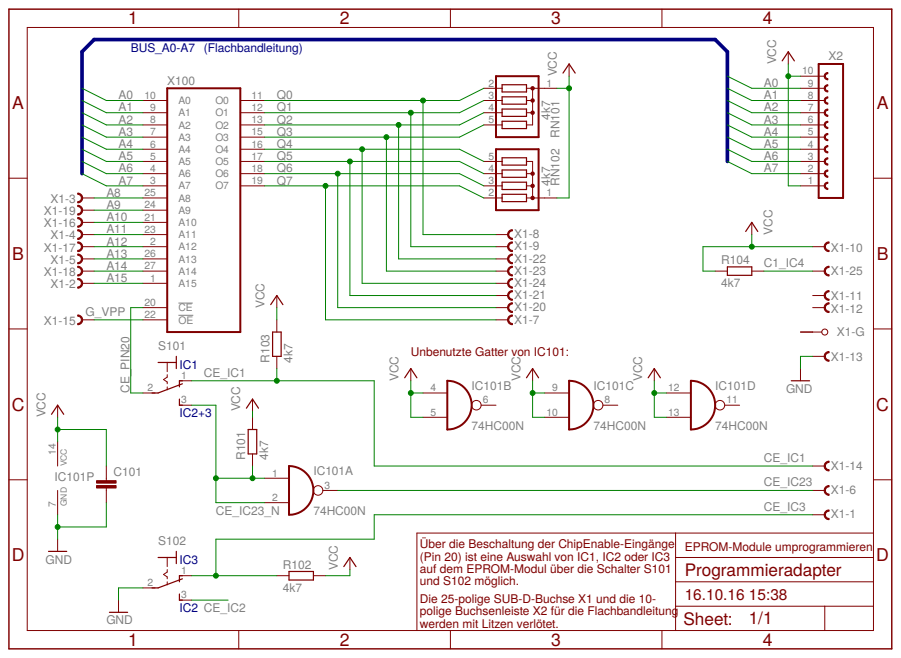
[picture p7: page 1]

BUS_A0-A7 (Flachbandleitung)

Über die Beschaltung der ChipEnable-Eingänge
(Pin 20) ist eine Auswahl von IC1, IC2 oder IC3
auf dem EPROM-Modul über die Schalter S101

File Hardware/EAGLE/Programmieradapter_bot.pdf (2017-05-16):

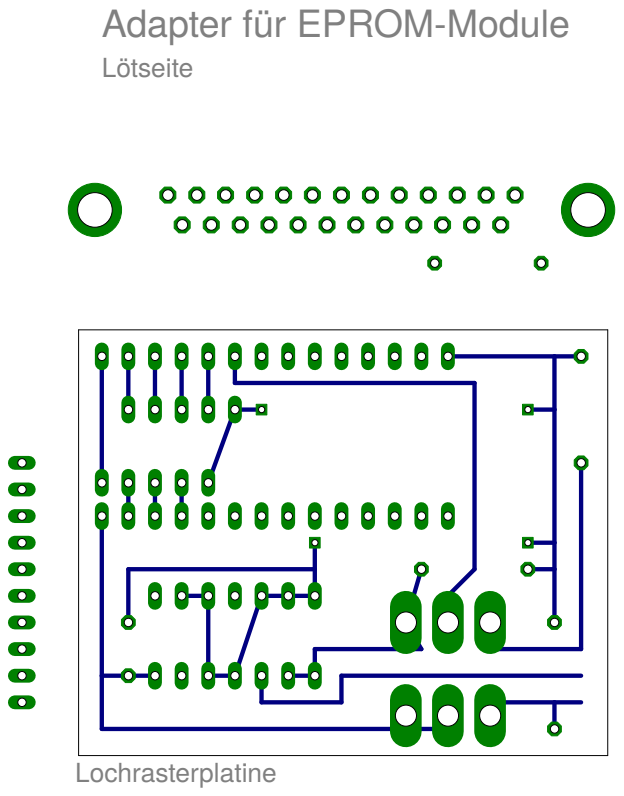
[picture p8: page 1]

Adapter für EPROM-Module
Lötseite

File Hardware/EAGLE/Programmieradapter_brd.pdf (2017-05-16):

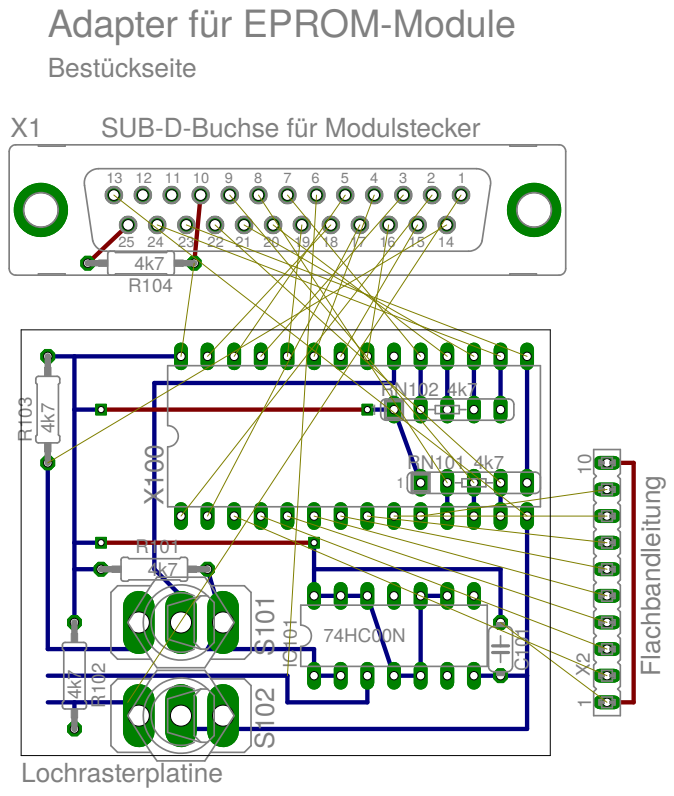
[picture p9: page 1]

Adapter für EPROM-Module
Bestückseite
SUB-D-Buchse für Modulstecker

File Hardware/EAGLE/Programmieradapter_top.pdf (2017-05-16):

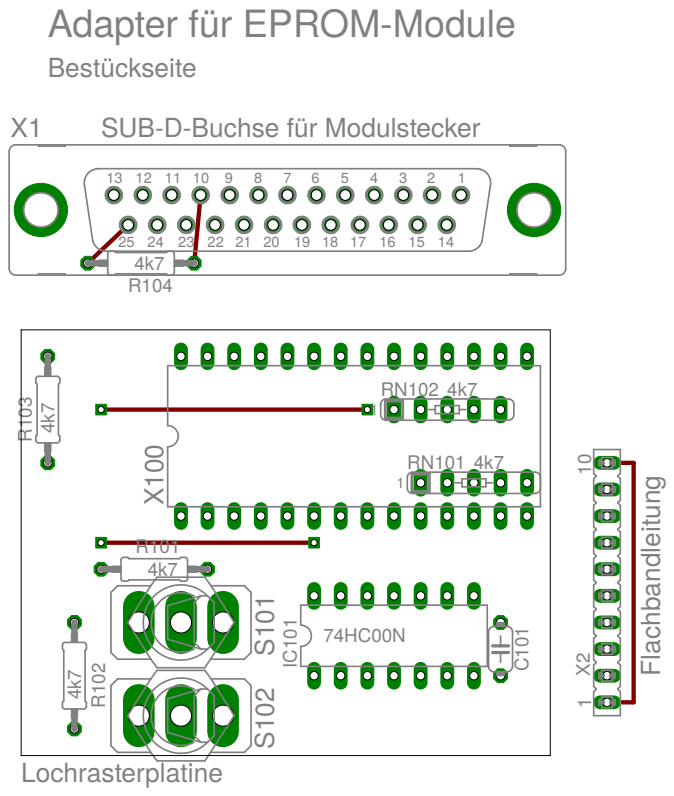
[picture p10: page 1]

Adapter für EPROM-Module
Bestückseite
SUB-D-Buchse für Modulstecker

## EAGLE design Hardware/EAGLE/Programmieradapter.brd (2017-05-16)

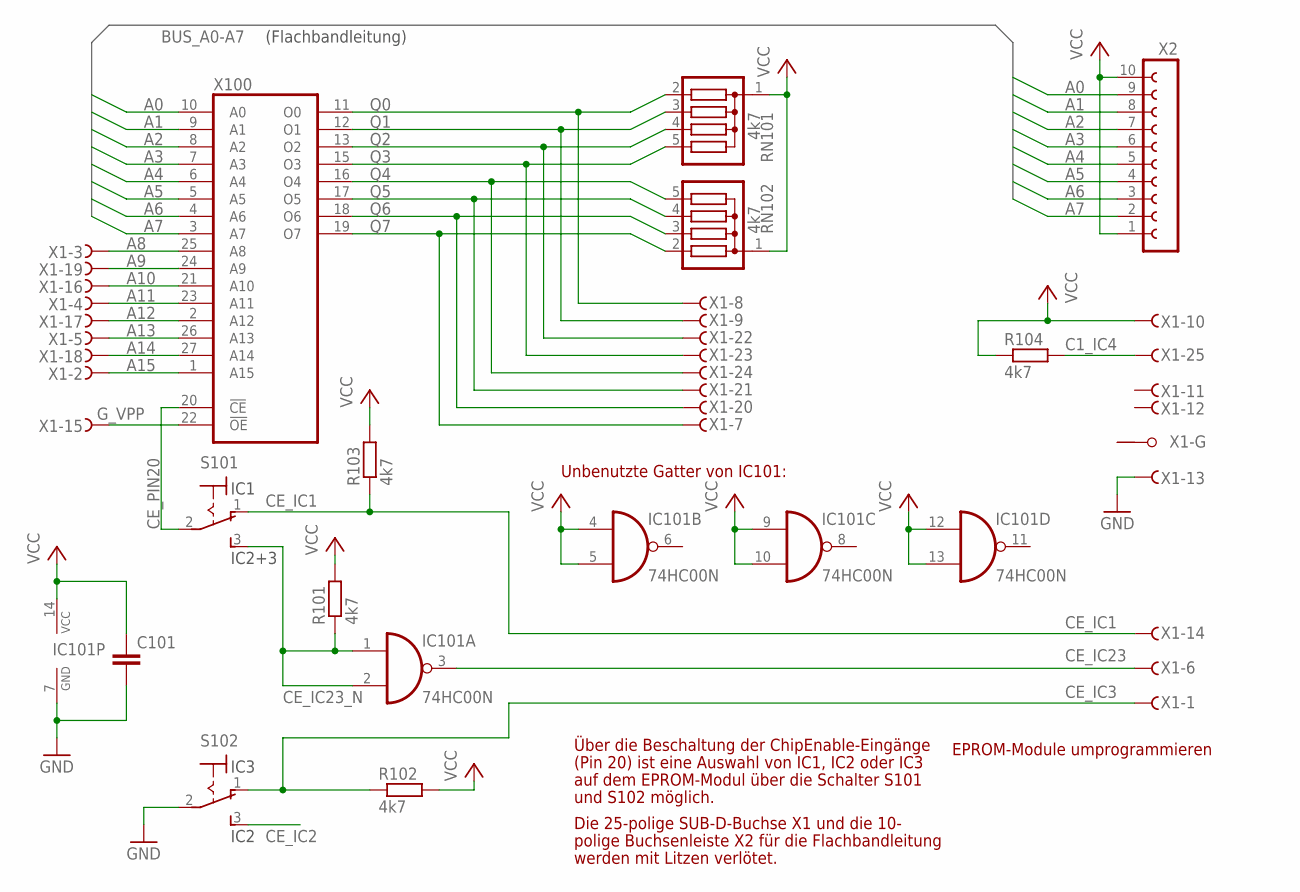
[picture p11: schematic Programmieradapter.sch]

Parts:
C101: C-EU050-024X044; C050-024X044
IC101: 74HC00N; DIL14
R101, R102, R103, R104: 4k7; 0207/10
RN101, RN102: 4k7; SIL5
S101, S102: 320-916
X1: F25VPS; F25VP
X2: FE10-1; FE10
X100: 27512; DIL28

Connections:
A0: X2.9, X100.10 (A0)
A1: X2.8, X100.9 (A1)
A2: X2.7, X100.8 (A2)
A3: X2.6, X100.7 (A3)
A4: X2.5, X100.6 (A4)
A5: X2.4, X100.5 (A5)
A6: X2.3, X100.4 (A6)
A7: X2.2, X100.3 (A7)
A8: X1.3 (F), X100.25 (A8)
A9: X1.19 (F), X100.24 (A9)
A10: X1.16 (F), X100.21 (A10)
A11: X1.4 (F), X100.23 (A11)
A12: X1.17 (F), X100.2 (A12)
A13: X1.5 (F), X100.26 (A13)
A14: X1.18 (F), X100.27 (A14)
A15: X1.2 (F), X100.1 (A15)
C1_IC4: R104.2, X1.25 (F)
CE_IC1: R103.1, S101.1 (O), X1.14 (F)
CE_IC2: S102.3 (S)
CE_IC3: R102.1, S102.1 (O), X1.1 (F)
CE_IC23: IC101.3 (O), X1.6 (F)
CE_IC23_N: IC101.1 (I0), IC101.2 (I1), R101.1, S101.3 (S)
CE_PIN20: S101.2, X100.20 (!CE)
GND: C101.2, IC101.7 (GND), S102.2, X1.13 (F), X100.14 (GND)
G_VPP: X1.15 (F), X100.22 (!OE)
Q0: RN101.2, X1.8 (F), X100.11 (O0)
Q1: RN101.3, X1.9 (F), X100.12 (O1)
Q2: RN101.4, X1.22 (F), X100.13 (O2)
Q3: RN101.5, X1.23 (F), X100.15 (O3)
Q4: RN102.5, X1.24 (F), X100.16 (O4)
Q5: RN102.4, X1.21 (F), X100.17 (O5)
Q6: RN102.3, X1.20 (F), X100.18 (O6)
Q7: RN102.2, X1.7 (F), X100.19 (O7)
VCC: C101.1, IC101.4 (I0), IC101.5 (I1), IC101.9 (I0), IC101.10 (I1), IC101.12 (I0), IC101.13 (I1), IC101.14 (VCC), R101.2, R102.2, R103.2, R104.1, RN101.1, RN102.1, X1.10 (F), X2.1, X2.10, X100.28 (VCC)

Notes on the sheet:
IC1
IC2+3
IC2
IC3
Über die Beschaltung der ChipEnable-Eingänge
(Pin 20) ist eine Auswahl von IC1, IC2 oder IC3
auf dem EPROM-Modul über die Schalter S101
und S102 möglich.
EPROM-Module umprogrammieren
Unbenutzte Gatter von IC101:
(Flachbandleitung)
Die 25-polige SUB-D-Buchse X1 und die 10-
polige Buchsenleiste X2 für die Flachbandleitung
werden mit Litzen verlötet.

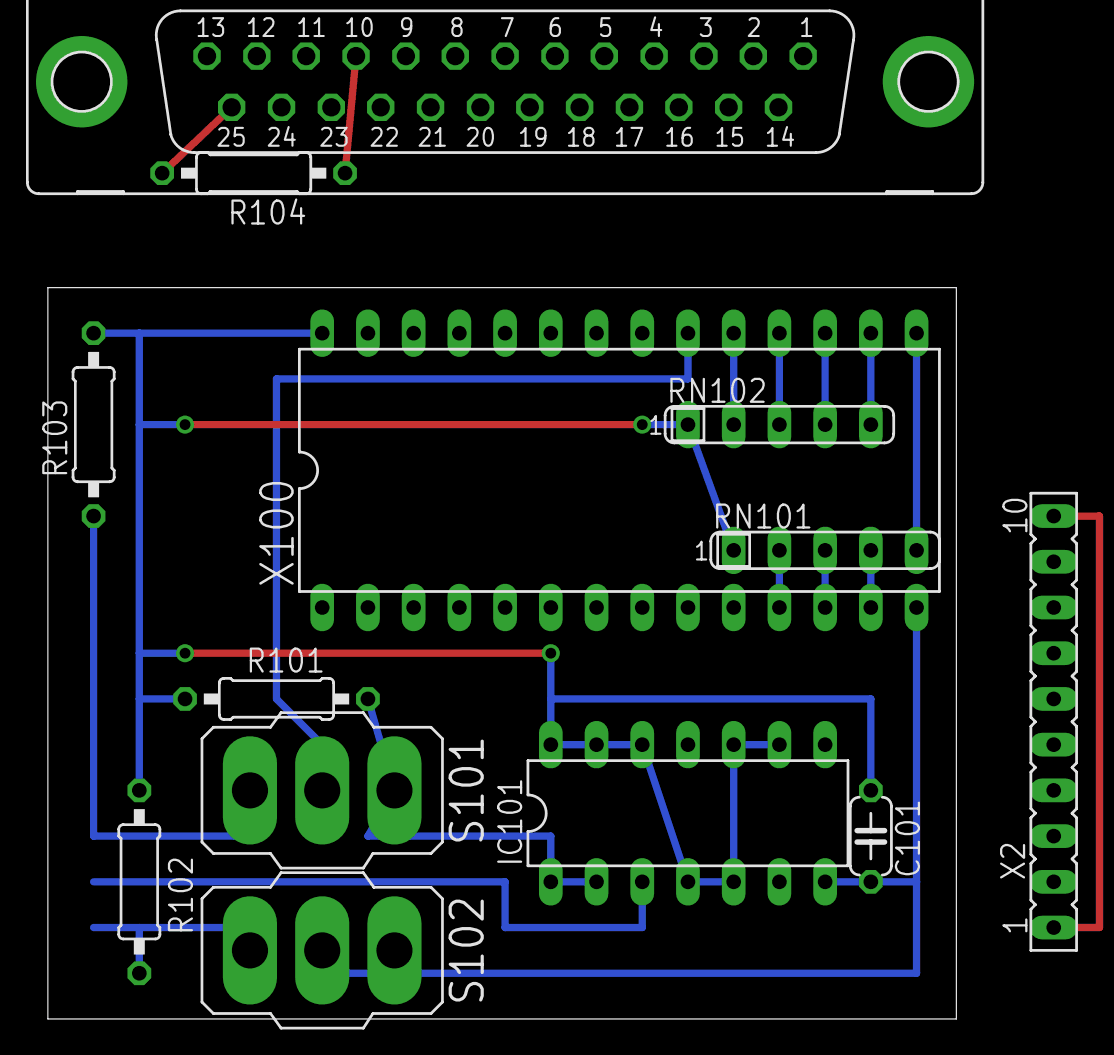
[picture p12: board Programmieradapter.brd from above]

Board: 2 copper layers, 50.5 x 40.6 mm, 13 parts (0 on the bottom side), 33 nets.
